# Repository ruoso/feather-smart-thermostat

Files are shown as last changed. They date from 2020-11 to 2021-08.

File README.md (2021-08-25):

# Feather smart thermostat

## Parts

 * a [feather huzzah](https://www.adafruit.com/product/3619)
 
 * a [2.13 e-ink monochrome](https://www.adafruit.com/product/4195)
   wing
 
 * a [I2C SHT31-D](https://www.adafruit.com/product/2857) temperature
   and humidity sensor
 
 * a single channel relay
 
 * a current sensor
 
 * three push buttons
 
 * safety "temperature is too low" disc thermostat
 
 * safety "temperature is too high" disc thermostat

## Design Approach

### "Dumb" safety

Safety thermostats override the system to always turn on when it's
getting too cold and always turn off when it gets too hot. This will
be achieved by putting the "low temperature" thermostat in parallel
with the relay that is fed from the smart part of the thermostat, then
connect them both in serial with the "high termperature" thermostat.

Those are driven by fixed-temperature disc thermostats.

### Monitor Current

Since the safety thermostats may trigger the current on or off
independently of the "smart" logic, we will monitor and report the
themperature so we can tell what the real state is.

### Stand-alone device

The thermostat will work as a stand-alone device first, with three
push buttons to raise and lower the set temperature as well as utility
functions, such as changing from celsius to farenheight or forcing a
reset.

### MQTT integration

The "smart" part of the thermostat will be driven by MQTT integrations
via wifi, the thermostat will publish data for:

 * Actual temperature
 * Actual humidity
 * Actual current
 * Relay status
 * Set temperature

And the thermostat will receive command for:

 * Set temperature

The idea is that it should always be possible to override the current
set temperature from the local device, and that should be reflected to
the automation system, while at the same time it should be possible
for the automation system to override the manually set temperature.

### Configuration

This will read a json file named `thermostat.json` in the root of the sdcard.

The sample file below explains the expected format:

```
{
    "wifi": {
        "ssid": "",
        "password": ""
    },
    "mqtt": {
        "broker_host": "",
        "broker_port": 1883,
        "clientid": "",
        "username": "",
        "password": "",
        "topics": {
            "action": "",
            "actual_temperature": "",
            "actual_humidity": "",
            "actual_current": "",
            "target_temperature": "",
            "ramp_up_buffer": "",
            "cool_down_buffer": "",
            "temperature_command": ""
        }
    },
    "temperature": {
        "starting": 21,
        "variance": 1,
        "ramp_up_buffer": 0.1,
        "cool_down_buffer": 0.1
    }
}

```

Most items are self-explanatory. The temperature section requires some explanation:

 * `starting`: Value of target temperature on reset, such as when
   returning from a power outage.

 * `variance`: This configures how wide should the control allow the
   temperature to vary. For instance, if you have the target set to
   21, and a variance set to 1, the ambient temperature should vary
   between 20.5 and 21.5 degrees.

 * `ramp_up_buffer` (Optional): How many degrees before the low end of
   the variance to turn the heater on, such that we don't get below
   the target variance due to the ramp up time of the heater
   element. This is the initial value, which will be automatically
   adjusted over time.

 * `cool_down_buffer` (Optional): How many degrees before the high end
   of the variance to turn the heater off, such that we don't get
   above the target variance due to residual heat after we turn the
   heater element off. This is the initial value, which will be
   automatically adjusted over time.

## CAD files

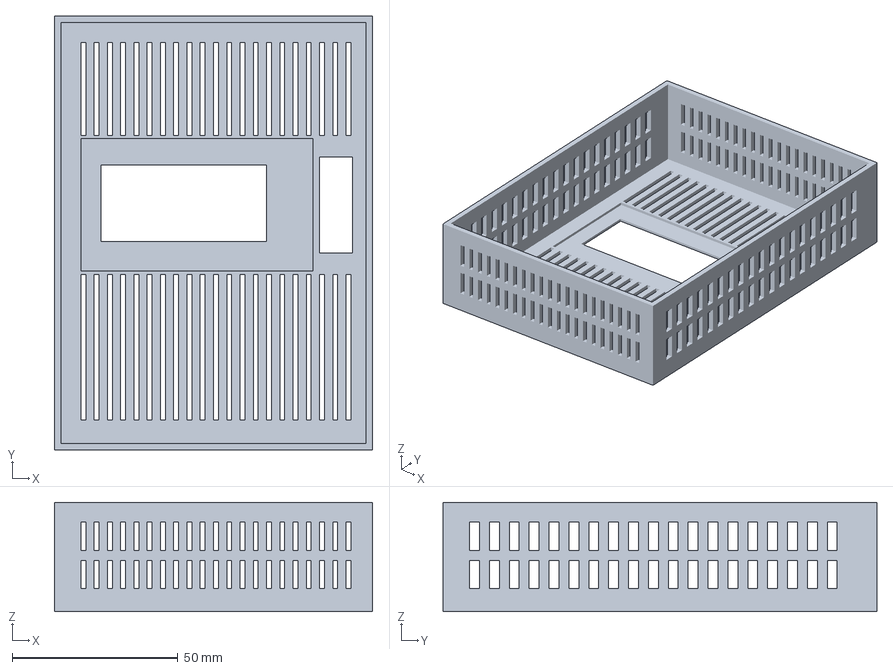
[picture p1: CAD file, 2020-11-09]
feather-smart-thermostat-cover.3mf
96.0 x 131.0 x 33.0 mm

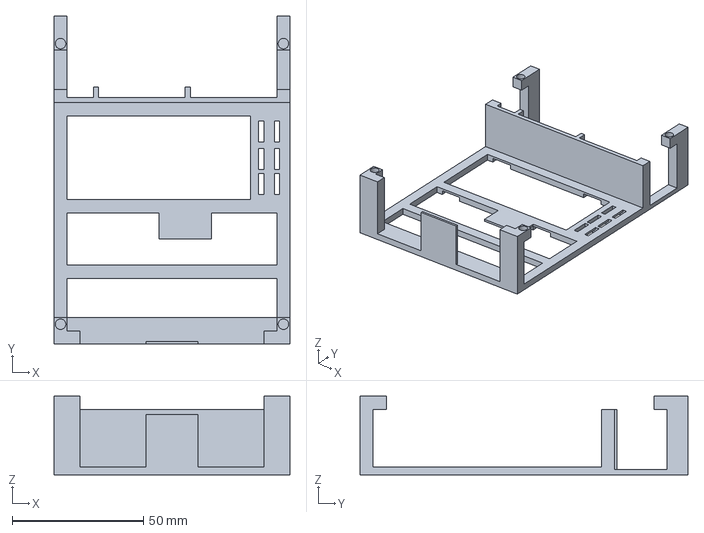
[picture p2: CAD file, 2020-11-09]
feather-smart-thermostat.3mf
90.0 x 125.0 x 30.0 mm

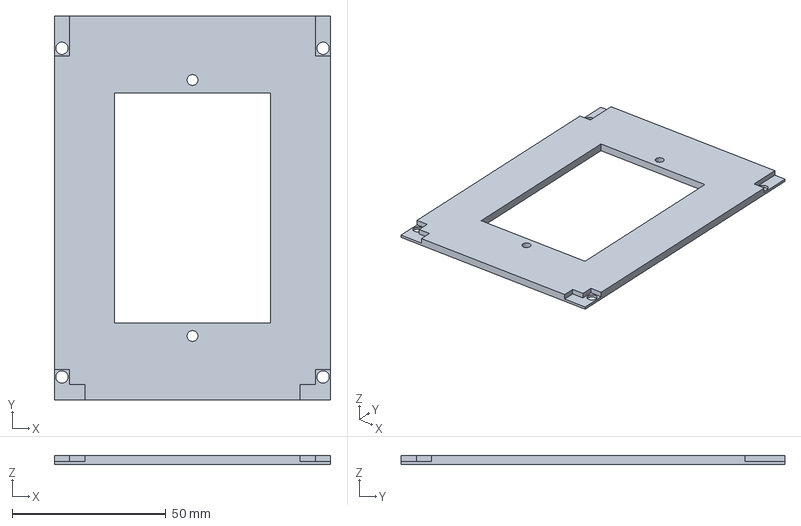
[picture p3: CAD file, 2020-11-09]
feather-smart-thermostat-wall-plate.3mf
90.0 x 125.0 x 3.00 mm

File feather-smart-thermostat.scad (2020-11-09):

module feather_epd_screwhole() {
    difference() {
        union() {
            translate([0,-1,0]) {
                cube([5,3.5,1]);
            }
            translate([2.5,2.5,0]) {
                cylinder(h=1, d=5, center=false, $fn=50);
            }
        }
        translate([2.5,2.5,0]) {
            cylinder(h=3, d=4.5, center=true, $fn=50);
        }
    }
}

module feather_epd_footprint() {
    union() {
        cube([60, 30, 20]);
        translate([5,0,0]) rotate(180) {
            feather_epd_screwhole();
        }
        translate([60, 0, 0]) rotate(180) {
            feather_epd_screwhole();
        }
        translate([0,30,0]) {
            feather_epd_screwhole();
        }
        translate([55,30,0]) {
            feather_epd_screwhole();
        }
    }
}


module component_mount_screwhole() {
    translate([2.5,2.5,0]) {
        cylinder(d=4, h=12, center=true, $fn=50);
    }
}
module component_mount_screwmount() {
    difference() {
        cube([5,5,5]);
        component_mount_screwhole();
    }
}
module button_mount_negative() {
    union() {
        cube([8,8,3]);
        cube([2,8,10]);
        translate([6,0,0]) cube([2,8,10]);
    }
}

module component_mount() {
    union() {
        difference() {
            cube([90,125, 30]); 

            // empty space in the bottom
            translate([10,-5,3]) cube([70,  92+5, 32]);

            // empty space in the sides
            translate([-1,5,3]) cube([100, 92-5, 32]);

            // area for power line
            translate([5,10,-1]) cube([80, 15, 32]);

            // area for lower line
            translate([5,30,-1]) cube([80, 20,32]);

            // screen
            translate([5,55,-1]) cube([70, 32, 32]);
            translate([7,50,-1]) cube([10,10,3]);
            translate([7,82,-1]) cube([10,10,3]);
            translate([7+53,50,-1]) cube([10,10,3]);
            translate([7+53,82,-1]) cube([10,10,3]);
            
            // buttons
            translate([78,57,-1]) button_mount_negative(); 
            translate([78,66.5,-1]) button_mount_negative();
            translate([78,77,-1]) button_mount_negative();

            // area for power adapter
            translate([5,92+2,-1]) cube([80, 35,32]);
            
            // sides of power adapter
            translate([-1,97,2]) cube([95,20,32]);

            // reduced depth of power adapter
            translate([-1,89,25]) cube([95,25,10]);
        }

        // support for power adapter
        translate([15,92.9,0]) cube([2,5,25]);
        translate([15+35,92.9,0]) cube([2,5,25]);

        // support for temp sensor
        translate([40,40,2]) cube([20,12,1]);
        
        // support for line connector
        translate([35,0,3]) cube([20,1,20]);

        translate([0,5,25]) component_mount_screwmount();
        translate([85,5,25]) component_mount_screwmount();
        translate([0,112,25]) component_mount_screwmount();
        translate([85,112,25]) component_mount_screwmount();
    }
}

module wall_mount() {
    union() {
        difference() {
            cube([90,125, 3]); 
            translate([(90/2)-(50.8/2),(125/2)-(75/2),-1])
                cube([50.8,75,5]);
            translate([0,0,-28]) component_mount();
            translate([(90/2),(125/2)-(83.34/2),-1])
                cylinder(h=5,d=3.5,$fn=50);
            translate([(90/2),(125/2)+(83.34/2),-1])
                cylinder(h=5,d=3.5,$fn=50);
            translate([0,5,-1]) component_mount_screwhole();
            translate([85,5,-1]) component_mount_screwhole();
            translate([0,112,-1]) component_mount_screwhole();
            translate([85,112,-1]) component_mount_screwhole();
        }
    }
}

module external_cover() {
    union() {
        difference() {
            translate([-3,-3,-2]) cube([96,131, 33]); 
            translate([-1,-1,0]) cube([92,127, 35]);
            
            translate([77,56.5,-5]) cube([10, 29, 33]);

            translate([5,51,-1]) cube([70, 91-51, 28.5]);
            translate([11,60,-5]) cube([50, 23, 28.5]);
            difference() {
                union() {
                    // front grills
                    difference() {
                        for (i=[5:4:86]) {
                            translate([i,92,-5]) cube([1.5,55,30]);
                            translate([i,-5,-5]) cube([1.5,55,30]);
                        }
                        translate([-4,-4,-5]) cube([120,10,10]);
                        translate([-4,120,-5]) cube([120,10,10]);
                    }
                    // side grills
                    for (i=[5:6:115]) {
                        translate([-5,i,5]) cube([10,3,20]);
                        translate([90,i,5]) cube([10,3,20]);
                    }
                }
                translate([-5,-5,15-1.5]) cube([100,150,3]);
            }
        }
    }
}

//mirror([0,0,1]) {
    
    //translate([0,0,28])
    //    wall_mount();
    
    //mirror([0,0,1])
    //translate([0,0,-27])
        //component_mount();
    //translate([0,0,-30])
        external_cover();
//}

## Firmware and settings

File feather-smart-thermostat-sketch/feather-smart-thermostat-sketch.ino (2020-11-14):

/***************************************************
 * Quote Display for Adafruit ePaper FeatherWings
 * For use with Adafruit tricolor and monochrome ePaper FeatherWings
 * 
 * Adafruit invests time and resources providing this open source code.
 * Please support Adafruit and open source hardware by purchasing
 * products from Adafruit!
 * 
 * Written by Dan Cogliano for Adafruit Industries
 * Copyright (c) 2019 Adafruit Industries
 * 
 * Notes: 
 * Update the secrets.h file with your WiFi details
 * Uncomment the ePaper display type you are using below.
 * Change the SLEEP setting to define the time between quotes
 */
#define BUSIO_USE_FAST_PINIO 1

#include "ThermostatConfig.h"
#include "ThermostatSDCard.h"
#include "ThermostatState.h"
#include "ThermostatControl.h"
#include "ThermostatUI.h"
#include "ThermostatNetworking.h"

Thermostat::State state;
Thermostat::Config config;
Thermostat::SDCard sdcard;
Thermostat::Control control;
Thermostat::UI ui;
Thermostat::Networking networking;
int quiet_log_control = 0;

void setup() {
  Serial.begin(115200);
  delay(1000);

  Serial.println("Starting configuration");
  try {
    sdcard.setup(config);
  } catch (...) {
    Serial.println("Unhandled exception when loading from sdcard");
  }
  if (config.loaded) {
    state.set_temperature = config.temperature_starting;
    state.variance = config.temperature_variance;
    state.ramp_up_buffer = config.ramp_up_buffer;
    state.cool_down_buffer = config.cool_down_buffer;

    Serial.println("Starting networking");
    networking.setup(config);
  }

  Serial.println("Starting control");
  control.setup();

  Serial.println("Starting UI");
  ui.setup();

  Serial.println("Setup complete");
}

void loop() {
  ui.input(state);
  control.update(state);
  ui.update(state);
  if (config.loaded) {
    networking.update(state);
  }
  if (quiet_log_control++ % 100 == 0) {
    Serial.println("Temperature: " + String(state.actual_temperature) + ", Humidity: " + String(state.actual_humidity) + " Relay: "+String(state.relay_state)+" Set: "+String(state.set_temperature));
  }
}

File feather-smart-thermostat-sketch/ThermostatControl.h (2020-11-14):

#ifndef INCLUDED_THERMOSTAT_CONTROL_H
#define INCLUDED_THERMOSTAT_CONTROL_H

#include <cmath>

#include <Adafruit_SHT31.h>
#include "ThermostatState.h"
#include "ThermostatConfig.h"

namespace Thermostat {

  struct Output {
    const static int pin = 21;
    Output() {
    }
    void setup() {
      pinMode(pin, OUTPUT);
    }
    void update(const State& state) {
      digitalWrite(pin, state.relay_state);
    }
  };

  struct Sensors {
    Adafruit_SHT31 sht31;
    const static int current_a_pin = 39;
    float moving_samples[10] = {0,0,0,0,0,0,0,0,0,0};
    int moving_samples_index = 0;
    int quiet_log_control = 0;
    Sensors() {
    }
    void setup() {
      pinMode(current_a_pin, INPUT);
      sht31.begin(0x44);
    }
    void update(State& state) {
      state.actual_temperature = sht31.readTemperature();
      state.actual_humidity = sht31.readHumidity();

      // 3. The module can measure the positive and negative 20 amps, corresponding to the analog output 100mV / A;
      // 4. There is no the detection current through, the output voltage is VCC / 2;
      // These analog input pins have 12-bit resolution. This means that when you read an analog input, its range may vary from 0 to 4095.
      int measured = analogRead(current_a_pin);
      float normalized = round(((measured * 3.2)/4096)*10)/10;
      float centered = normalized - 1.5;

      // The CPU is already too busy for us to be able to read AC and calculate it correctly. So instead we'll just check that
      // the variance we have had was bigger than 0.1 over the past 10 measurements, which will most definitely be always true
      // when we have current, and always false when we don't.
      moving_samples[moving_samples_index%10] = abs(centered);
      int sample_count = moving_samples_index > 9 ? 10 : moving_samples_index + 1;
      float sum = 0;
      for (int i = 0; i < 10 && i <= moving_samples_index; i++) {
        sum += moving_samples[i];
      }
      float avg = sum / sample_count;
      float variance = 0;
      for (int i = 0; i < 10 && i <= moving_samples_index; i++) {
        float difference = moving_samples[i] - avg;
        variance += difference * difference;
      }

      if (variance > 0.01) {
        state.actual_current = 1;
      } else {
        state.actual_current = 0;
      }

      if (quiet_log_control++ % 100 == 0) {
        Serial.println("Current samples avg: " + String(avg) + ", variance: " + String(variance) + " Result: "+String(state.actual_current));
      }
      moving_samples_index++;
    }
  };
  
  struct Control {
    Output output;
    Sensors sensors;
    float temp_on_last_change;
    Control() {
    }
    void setup() {
      output.setup();
      sensors.setup();
    }
    void update(State& state) {
      sensors.update(state);
      if (!std::isnan(state.max_temperature_since_state_set_to_idle)) {
        // let's record how high temperature went since the last cycle
        state.max_temperature_since_state_set_to_idle = std::max(state.actual_temperature, state.max_temperature_since_state_set_to_idle);
      }
      if (!std::isnan(state.min_temperature_since_state_set_to_heat)) {
        // let's record how low the temperature went since the last cycle
        state.min_temperature_since_state_set_to_heat = std::min(state.actual_temperature, state.min_temperature_since_state_set_to_heat);
      }
      if (state.relay_state == 0) {
        if (state.actual_temperature < ((state.set_temperature - state.variance/2)+state.ramp_up_buffer)) {
          if (!std::isnan(state.max_temperature_since_state_set_to_idle)) {
            // we went through a full cycle after turning it on, turning it off, so we now can
            // update the cool_down_buffer, based on the difference between the temperature set when we set to idle
            // versus the max temperature
            state.cool_down_buffer = state.max_temperature_since_state_set_to_idle - state.temperature_on_last_state_set_to_idle;
          }
          state.relay_state = 1;
          state.temperature_on_last_state_set_to_heat = state.actual_temperature;
          state.min_temperature_since_state_set_to_heat = state.actual_temperature;
        }
      } else {
        if (state.actual_temperature > ((state.set_temperature + state.variance/2)-state.cool_down_buffer)) {
          if (!std::isnan(state.min_temperature_since_state_set_to_heat)) {
            // we went through a full cycle after turning it off, turning it on, so we now can
            // update the ramp_up_buffer, based on the difference between the temperature set when we set to heat
            // versus the min temperature
            state.ramp_up_buffer = state.temperature_on_last_state_set_to_heat - state.min_temperature_since_state_set_to_heat;
          }
          state.relay_state = 0;
          state.temperature_on_last_state_set_to_idle = state.actual_temperature;
          state.max_temperature_since_state_set_to_idle = state.actual_temperature;
        }
      }
      output.update(state);
    }
  };

}

#endif

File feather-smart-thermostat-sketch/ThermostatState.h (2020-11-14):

#ifndef INCLUDED_THERMOSTAT_STATE_H
#define INCLUDED_THERMOSTAT_STATE_H

#include <cmath>

namespace Thermostat {
  struct State {
    float actual_temperature;
    float actual_humidity;
    float actual_current;
    bool  relay_state;
    bool  wifi_online;
    bool  mqtt_online;
    bool  convert_temperature_to_f;
    float set_temperature = 12;
    float variance = 1;
    float temperature_on_last_state_set_to_idle = std::nanf("");
    float max_temperature_since_state_set_to_idle = std::nanf("");
    float temperature_on_last_state_set_to_heat = std::nanf("");
    float min_temperature_since_state_set_to_heat = std::nanf("");
    float ramp_up_buffer = 0;
    float cool_down_buffer = 0;
  };
}

#endif

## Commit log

2020-10-12 store what is in the protoboard
    [feather-smart-thermostat.sch]
2020-10-12 have an example code that works
    Also customize the driver to reduce the update time to 1s instead of the amount it was taking before
    [feather-smart-thermostat.sch]
2020-10-16 Out of example code. State, Control and UI done
    [_saved_feather-smart-thermostat.sch]
2020-10-17 use the current sensor
    Also change some pins since we cannot use ADC2
    [feather-smart-thermostat.sch]
2020-10-17 minor fix in current moving average
    [ThermostatControl.h]
2020-10-18 start 3d modelling
    [feather-smart-thermostat.3mf, feather-smart-thermostat.scad]
2020-11-09 finished cover, fixed obvious problem by grounding digital pins
    [feather-smart-thermostat-cover.3mf, feather-smart-thermostat-wall-plate.3mf, feather-smart-thermostat.3mf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]
2020-11-14 ramp-up/cool-down
    Implement logic to adjust the behavior depending on how much
    temperature still rises after turning the heat off, or how
    much it lowers after turning the heat on.
    It supports an initial value, but it will continue adjusting
    as it goes so it can better fit the goal variance.
    This has managed to very precisely keep the temperature within
    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
2020-11-14 try to get a better current result
2020-11-14 improve current reporting
